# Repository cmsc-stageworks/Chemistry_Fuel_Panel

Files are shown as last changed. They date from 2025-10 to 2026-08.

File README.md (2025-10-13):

# Chemistry Fuel Panel
The chemistry fuel panel will be interacted with using a prop canister that is inserted into several holes in the panel. Each hole can use a pair of hall effect sensors to detect both the presense and direction of the canister. The canister will rotate freely in some holes which can be used as a selection mechanism, and it will lock in others to test if you have successfully completed the puzzle. Each of the free spinning holes will allow you to "select a gas level" for whatever that hole contains e.g. Oxygen. There will be a ring of leds around the hole that can give a visual readout of how much gas they are filling the canister with alongside a button to confirm that they have the desired gas level. Once mixing is complete they can insert the canister into the locking output to see if their chemistry experiment was a success. Some puzzles could be very easy, only requiring the correct balance of plain elements, while some could mix more complex chemicals and have to balance the pressure in the canister.

On the panel an LCD screen will show which chemicals are currently assigned to each filling port (the free spinning ones), the desired product chemical, and any other information that may change on the fly and can't be communicated with just the lights. There would be a manual with instructions on how to use the panel alongside some useful resources like a periodic table and some example problems.

If there is enough time and space we might even add a way to fuel the ship's generators by synthesysing fuel right at the chemistry panel and filling up the generator. They might also need to route power or manage waste products from the generator.

##  Parts
- 10 hall effect sensors 
- 5 ring lights, 1 per hole in the panel
- LCD screen
- 3 buttons
- 3 12v solenoid cabinet locks
- 1 Really long LED strip

## Diagram
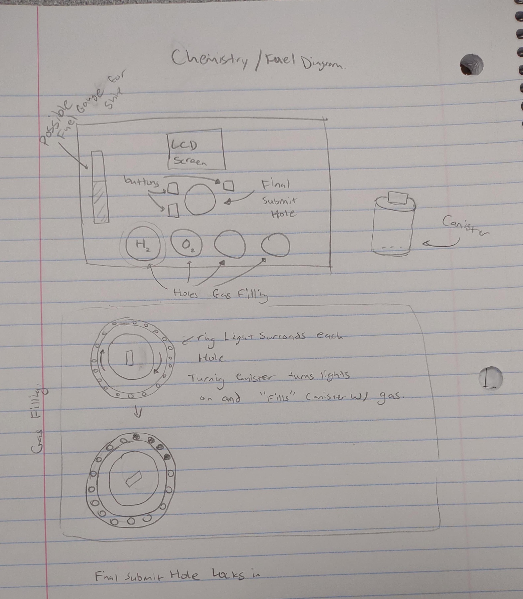
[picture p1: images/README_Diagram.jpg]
Diagram


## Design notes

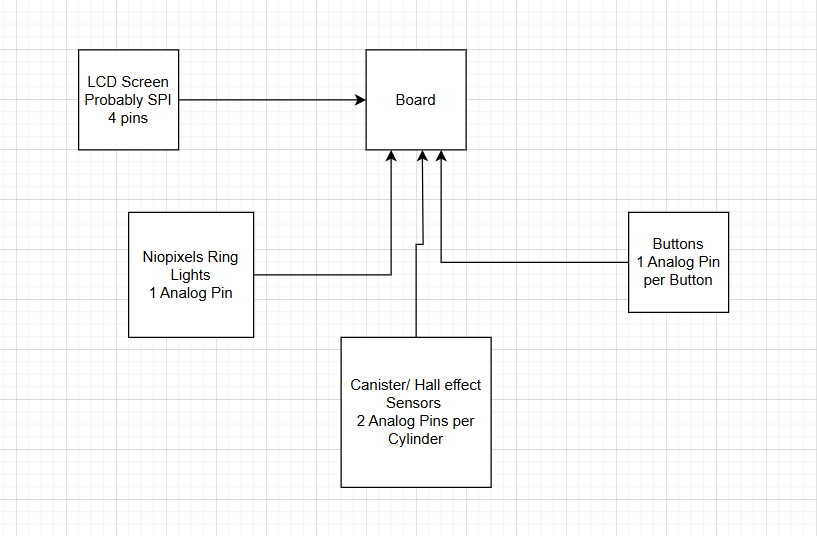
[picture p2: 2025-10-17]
images/Flow Chart Diagram.png

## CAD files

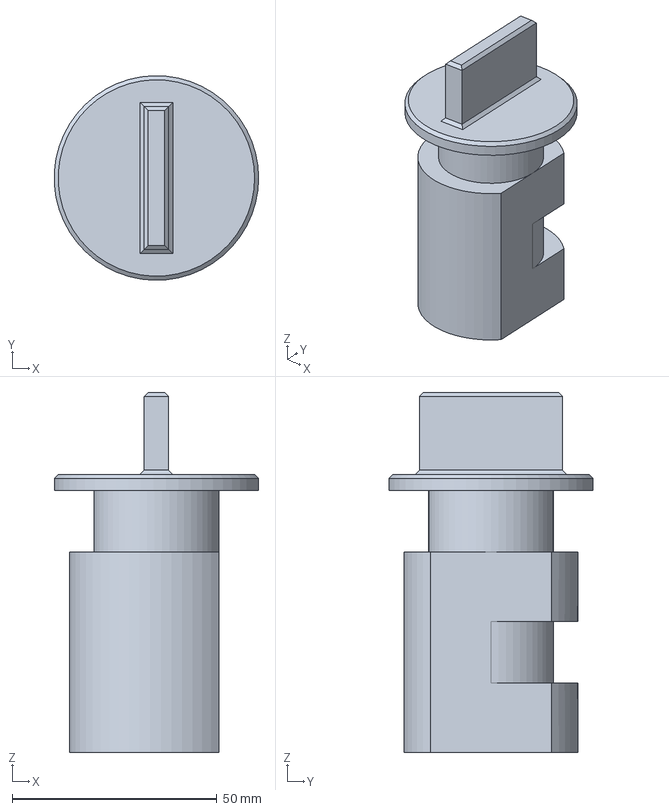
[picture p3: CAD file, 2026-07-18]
Models/Canister.FCStd
50.0 x 50.0 x 88.0 mm

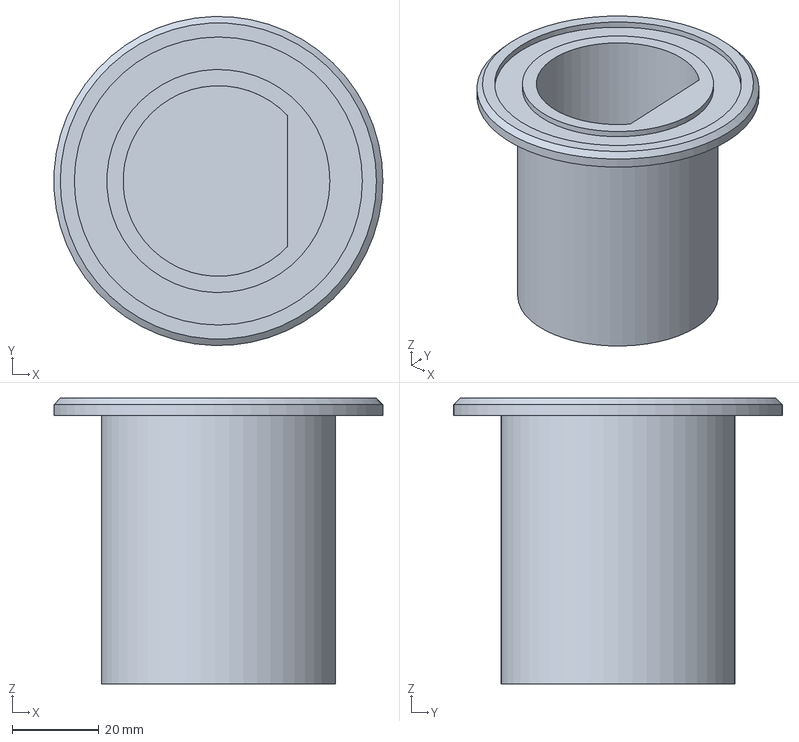
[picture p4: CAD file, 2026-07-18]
Models/Recepticle.FCStd
75.9 x 76.0 x 66.0 mm

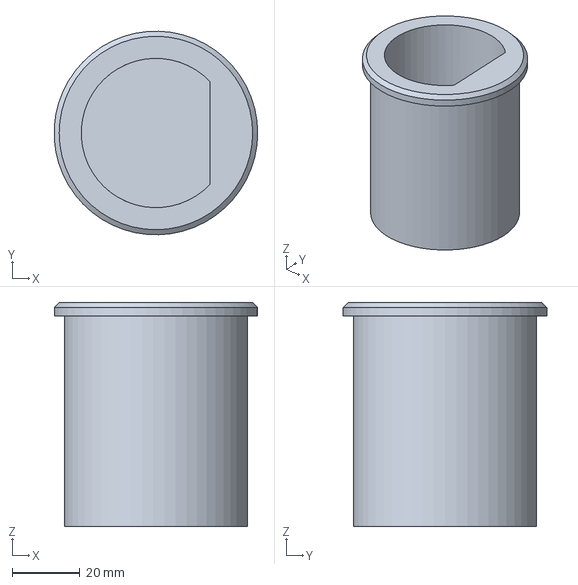
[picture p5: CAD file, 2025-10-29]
Models/Locking Recepticle.FCStd
59.9 x 60.0 x 66.0 mm

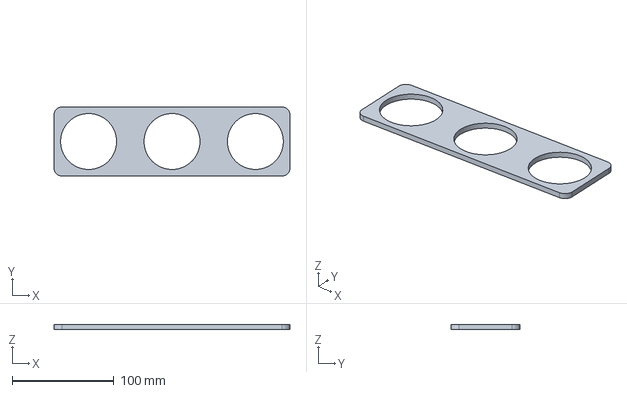
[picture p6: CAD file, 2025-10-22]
Models/Plate.FCStd
232.0 x 68.0 x 5.00 mm

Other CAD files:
Models/Face Plate.stl
Models/Canister.stl
Models/Locking Recepticle.stl
Models/Recepticle.stl

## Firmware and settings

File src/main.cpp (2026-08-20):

#include "HardwareSerial.h"
#include "pins_arduino.h"
#include "MainBoardPinout.h"
#include "MainBoard.h"
#include <SPI.h>
#include <Arduino.h>
#include <Wire.h>
#include <Adafruit_SSD1306.h>
#include <Adafruit_NeoPixel.h>
#include <Adafruit_ST7796S.h>
#include <cstdint>
#include <sys/types.h>

#define NUMPIXELS 16

#define HALL1 0x48
#define HALL2 0x49

#define M_PI 3.14159265358979323846

#define INPUT_THRESHOLD 20.0

#define OLED_ADDRESS 0x3C
#define OLED_WIDTH 128
#define OLED_HEIGHT 64

#define PUZZLE_COUNT 6

typedef struct{

    char chem1[9];
    char chem2[9];
    char chem3[9];

    uint8_t amount1;
    uint8_t amount2;
    uint8_t amount3;

    char outputChemical[21];

}Puzzle;

Puzzle puzzleCreate(const char* c1, const char* c2, const char* c3, uint8_t r1, uint8_t r2, uint8_t r3, const char* out){
    Puzzle p;
    strcpy(p.chem1, c1);
    strcpy(p.chem2, c2);
    strcpy(p.chem3, c3);
    p.amount1 = r1;
    p.amount2 = r2;
    p.amount3 = r3;
    strcpy(p.outputChemical, out);
    return p;
}

int16_t hall[8] = {0};
uint16_t hallCalibration[8] = {0};

uint8_t hallPin[8] = {0x48,0x49,0x47,0x46,0x3f,0x3e,0x3c,0x3d};

uint8_t litLeds[3] = {0};

float angles[4] = {0};
float fieldStrength[4] = {0};

bool present[4] = {false};
bool inserted[4] = {false};
bool removed[4] = {false};

bool buttons[4] = {false};
bool buttonsPressed[4] = {false};

bool locked[4] = {false};

char chemicals[3][9]={{"H"},{"C"},{"O"}};
uint8_t ratios[3] = {12,6,6};
char target[21] = "";
float threshold = 0.8;

Puzzle allPuzzles[PUZZLE_COUNT];
uint8_t currentPuzzle = -1;

Adafruit_NeoPixel pixels(NUMPIXELS*3, MAIN_BOARD_WS2812_PIN, NEO_RGB + NEO_KHZ800);
Adafruit_SSD1306 display(128, 64, &Wire);
Adafruit_ST7796S bigDisplay(&mainBoardSpi, MAIN_BOARD_LCD_1_CS, MAIN_BOARD_LCD_DC, MAIN_BOARD_LCD_RESET);

void fillPuzzles(){
    allPuzzles[0] = puzzleCreate("H", "O", "", 2, 1, 0, "H2O");
    allPuzzles[1] = puzzleCreate("H", "C", "O", 12, 6, 6, "C6H12O6");
    allPuzzles[2] = puzzleCreate("H", "C", "", 8, 2, 0, "2CH4");
    allPuzzles[3] = puzzleCreate("CaCO3", "CO2", "H2O", 6, 6, 6, "6Ca(HCO3)2");
    allPuzzles[4] = puzzleCreate("SO2","O2","H2O", 2, 1, 2, "?H2SO4");
    allPuzzles[5] = puzzleCreate("Fe", "O2", "H2O", 4, 3, 6, "?Fe(OH)3");
}

void nextPuzzle(){

    currentPuzzle++;
    if (currentPuzzle > PUZZLE_COUNT - 1){
        currentPuzzle = 0;
    }

    Puzzle puzzle = allPuzzles[currentPuzzle];
    
    strcpy(chemicals[0], puzzle.chem1);
    strcpy(chemicals[1], puzzle.chem2);
    strcpy(chemicals[2], puzzle.chem3);

    strcpy(target, puzzle.outputChemical);

    ratios[0] = puzzle.amount1;
    ratios[1] = puzzle.amount2;
    ratios[2] = puzzle.amount3;

    litLeds[0] = 0; litLeds[1] = 0; litLeds[2] = 0;

    bigDisplay.setTextSize(3);
    bigDisplay.fillScreen(0xffff);
    bigDisplay.setTextColor(0,0xffff);
    bigDisplay.setCursor(50,100);
    bigDisplay.println("Make a chemical:");
    bigDisplay.setCursor(70,150);
    bigDisplay.println(target);

    pixels.fill(0,0,NUMPIXELS*3);
    pixels.show();

    litLeds[0] = 0;
    litLeds[1] = 0;
    litLeds[2] = 0;
    locked[0] = 0;
    locked[1] = 0;
    locked[2] = 0;
    
}

void validatePuzzle(){

    if(litLeds[0] == ratios[0] && litLeds[1] == ratios[1] && litLeds[2] == ratios[2]){

        bigDisplay.fillScreen(bigDisplay.color565(0, 255, 255));
        bigDisplay.setTextColor(0xffff,0);
        bigDisplay.print("Congrats!");

        for(uint8_t i = 0; i < NUMPIXELS*3; i++){
            pixels.setPixelColor(i, pixels.Color(120,0,0));
        }
        pixels.show();

        delay(3000);

        nextPuzzle();

    }
}

void setup(){
    MainBoardStart(false);

    mainBoardSpi.setFrequency(10000000);

    Wire.begin();

    Serial.begin(115200);
    pixels.begin();
    pixels.clear();
    pixels.show();

    delay(50);

    display.begin(SSD1306_SWITCHCAPVCC, OLED_ADDRESS);

    for(uint8_t i = 0; i < 3; i++){
        mainBoardSetI2CBus(i);
        display.begin(SSD1306_SWITCHCAPVCC, 0x3C);
        display.clearDisplay();
        display.setFont();
        display.setTextColor(1);
        display.setCursor(0, 0);
        display.print("init ");
        display.println(i);
        display.display();
    }


    for(uint8_t i = 0; i < 8; i++){
        hallCalibration[i] = mainBoardGetAnalogMux(hallPin[i]);
        Serial.print(hallCalibration[i]);
        Serial.print(", ");
    }
    Serial.println();

    Serial.println("Calibration complete");


    analogWrite(MAIN_BOARD_LCD_BRIGHTNESS, 0xFF);

    bigDisplay.init(320, 480, 0, 0, ST7796S_BGR);
    bigDisplay.setRotation(3);
    bigDisplay.invertDisplay(true);
    bigDisplay.fillScreen(0);

    delay(100);

    fillPuzzles();
    nextPuzzle();
    
}

void loop(){
    Serial.print("Halls");
    for (uint8_t i = 0; i < 8; i++){
        hall[i] = mainBoardGetAnalogMux(hallPin[i]) - hallCalibration[i];
        Serial.print(", ");
        Serial.print(hall[i]);
    }
    Serial.println();

    


    for(uint8_t i = 0; i < 4; i++){
        int h1 = hall[2*i];
        int h2 = hall[2*i+1];
        fieldStrength[i] = std::sqrt(h1*h1 + h2*h2);

        bool button = !mainBoardGetDigitalInput(i);

        buttonsPressed[i] = false;

        if(button){

            if(!buttons[i]){
                buttonsPressed[i] = true;
            }

        }

        buttons[i] = button;

        inserted[i] = false;
        removed[i] = false;

        if(fieldStrength[i] > INPUT_THRESHOLD){

            if(buttonsPressed[i] && !locked[i]){
                locked[i] = true;
            }else if(buttonsPressed[i]){
                locked[i] = false;
            }

            if(!locked[i]){
                angles[i] = std::atan2(hall[2*i], hall[2*i+1]) + M_PI;
            }

            if(!present[i]){
                inserted[i] = true;
                locked[i] = false;
            }
            present[i] = true;
        }else{
            if(present[i]){
                removed[i] = true;
            }
            present[i] = false;
        }

        Serial.print("A");
        Serial.print(i);
        Serial.print(": ");
        Serial.print(angles[i]);
        Serial.print(",   ");
        
    }
    Serial.println();

    

    for(uint8_t q = 0; q < 3; q++){

        litLeds[q] = std::min(static_cast<int>((angles[q] * NUMPIXELS / (2 * M_PI))) + 1, NUMPIXELS);

        if(fieldStrength[q] > INPUT_THRESHOLD){
            for(uint8_t i = NUMPIXELS * q; i < NUMPIXELS * q + litLeds[q]; i++){
                pixels.setPixelColor(i, pixels.Color(0,125,0));
            }

            for(uint8_t i = NUMPIXELS * (q) + litLeds[q]; i < NUMPIXELS * (q + 1); i++){
                pixels.setPixelColor(i, pixels.Color(0,0,0));
            }
            pixels.show();
        }else{
            if(locked[q]){
                for(uint8_t i = NUMPIXELS * q; i < NUMPIXELS * q + litLeds[q]; i++){
                    pixels.setPixelColor(i, pixels.Color(0,125,0));
                }

                for(uint8_t i = NUMPIXELS * (q) + litLeds[q]; i < NUMPIXELS * (q + 1); i++){
                    pixels.setPixelColor(i, pixels.Color(0,0,0));
                }
            }else{
                for(uint8_t i = NUMPIXELS * q; i < NUMPIXELS * (q+1); i++){
                    pixels.setPixelColor(i, pixels.Color(0,0,0));
                }
                litLeds[q] = 0;
            }
            pixels.show();

            
        }


        mainBoardSetI2CBus(q);
        display.clearDisplay();
        display.setTextSize(1);
        display.setCursor(0, 0);
        display.print("Concentration: ");
        display.println(litLeds[q]);
        display.setTextSize(4);
        display.println(chemicals[q]);
        display.setTextSize(1);
        display.print("Lock: ");
        display.print(locked[q]);
        display.display();


    }

    Serial.print("Present: ");
    Serial.print(present[3]);
    Serial.print(", Button: ");
    Serial.println(buttonsPressed[3]);

    if(buttonsPressed[3] && present[3] && angles[3] > 1.5){

        validatePuzzle();

        Serial.println("Validating!");

    }

}

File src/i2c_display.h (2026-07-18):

#include <Adafruit_SSD1306.h>
#include <Adafruit_GFX.h>

#define SDA_PIN 21
#define SCL_PIN 22
#define SCREEN_WIDTH 128 // OLED display width, in pixels
#define SCREEN_HEIGHT 64 // OLED display height, in pixels

void draw_element(Adafruit_SSD1306* display, String element, int num_element, String atomic_weight);

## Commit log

2025-10-16 Early Code
    - Added the prototype code for the canisters
2025-10-17 Flow Chart
2025-10-22 Added the 3D cad files
    All the following models are in the models folder in both FCStd (Free CAD) and stl versions.
    - Canister
    - Locking Recepticle
    - Recepticle
    - Face Plate
    [Canister.FCStd, Canister.stl, Face Plate.stl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]
2025-10-22 Fixed a few bugs when reading inputs.
    - Added INPUT_PULLUP for the button inputs.
    - Added several serial debug messages.
    - Removed the second redundant button check.
    [main.cpp]
2025-10-29 Updated canister 3D models
    [Canister.FCStd, Canister.stl, Locking Recepticle.FCStd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]
2025-11-14 i2c modifications including element display card
2025-11-19 added old_main.cpp
    - Realized I was accidentally updating the main.cpp in a different directory than the github repo so I coppied it over as old_main.cpp. I will work on moving my changes over to the newer one soon.
    - Updated cad files.
    [Canister.FCStd, Canister.stl]
2026-07-18 Added PCBs and added display libraries
    [HallSensorBoard.kicad_pcb, HallSensorBoard.kicad_sch, Recepticle.FCStd]
2026-07-18 Fixed thermal relief errors on ground
    [HallSensorBoard.kicad_pcb]
